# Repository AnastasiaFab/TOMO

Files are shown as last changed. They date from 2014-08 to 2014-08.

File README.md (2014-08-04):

TOMO

#### TOMO is a programmable Touch Synthesizer board based on Arduino. 

##### TOMO can sense your touch on many different materials and create sounds to tell people things.

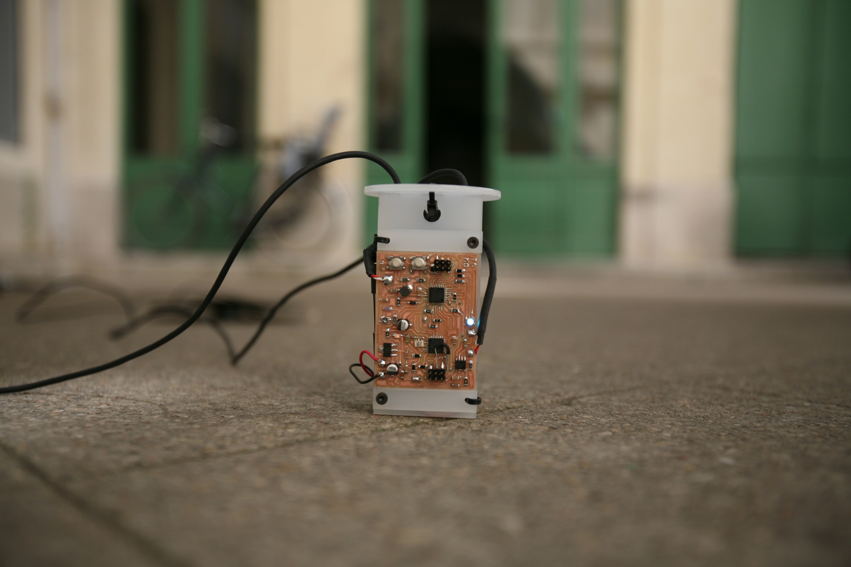
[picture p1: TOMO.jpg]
TOMO


### What is TOMO?

##TO

**TO** means touch. Tomo uses **Swept Frequency Capacitive Sensing (SFCS)** a concept explored by [Disney Research Labs](http://www.disneyresearch.com/) on this [paper](http://www.disneyresearch.com/wp-content/uploads/touchechi2012.pdf). The Arduino implementation is based on the documentation by [ILLUTRON](http://illutron.dk/Instructable-Use-Any-Surface-as-a-Touch-Interface-with-Arduino) and developed by [Cleniem](https://github.com/clemniem). The internal ongoing research on SFCS can be found at [fablabbcn/TouchE](https://github.com/fablabbcn/TouchE).

##MO

**MO** means [Mozzi](http://sensorium.github.io/Mozzi/) an amazing library for sound synthesis library for Arduino developed by [Tim Barrass](http://www.reverberant.com/pp/barrass.htm). This means you can create sounds with it from simple tones to delays and echos. We will soon add *.WAV palying functionality too.

### How is TOMO?

* Small
* Portable
* Easy
* Fun
* and it runs on batteries for a week!

### Project team:

This project was developed with the support of the [EASTN (The European Art-Science-Technology Network)](https://github.com/eastn.eu) at [Fab Lab Barcelona](http://www.fablabbcn.org/). The first real setup was done for the [FAV Festival](http://festivaldesarchitecturesvives.com/) in Monpellier in June 2014.

* [Cleniem](https://github.com/clemniem) 
* [Pral2a](https://github.com/pral2s)
* [Anastasia Pistofidou](https://github.com/anastasiafab)

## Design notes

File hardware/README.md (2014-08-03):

The TOMO board
==============

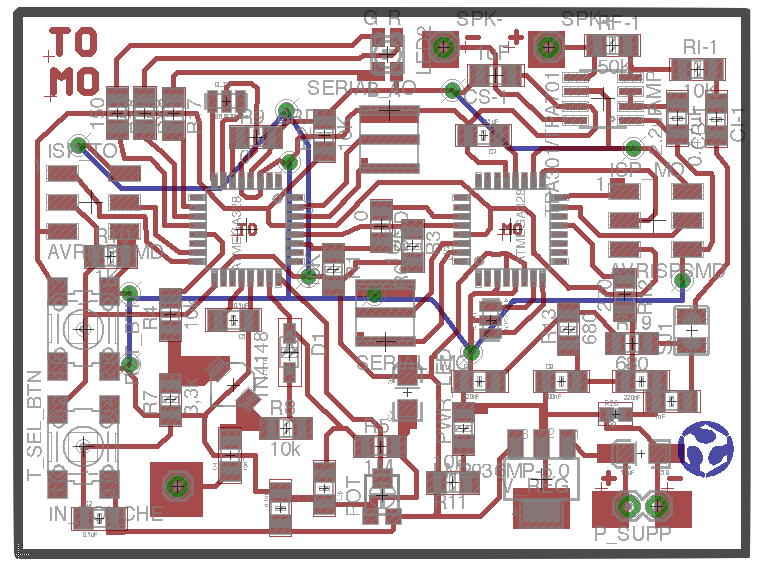
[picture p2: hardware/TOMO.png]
TOMO


Check the the Eagles and the PDF schematic for more information. 

Notice the PCB design is done to be milled on a PCB milling machine.

Check the CAM folder for the PNG for [FabModules](http://kokompe.cba.mit.edu/).

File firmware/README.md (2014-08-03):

The TOMO code
=============

**TOMO** has two processors this means it runs two separate firmwares: one for touch and one for sound.

## Firmware

Check the **TO** folder for the Touch firmware and the **MO** folder for the Mozzi Sound firmware. The sound firmware is currently a boilerplate for you to create your new sounds. Check on the **mozzi tests** folder for more examples.

* Touch firmware: `TOMO_Touch_v05.ino`

* Sound firmware: `TOMO_Mozzi_v05.ino` 

### Dependencies

All firmware is based on the Arduino Core. For the Mozzi firmware it requires the [Mozzi library](sensorium.github.io/Mozzi/)

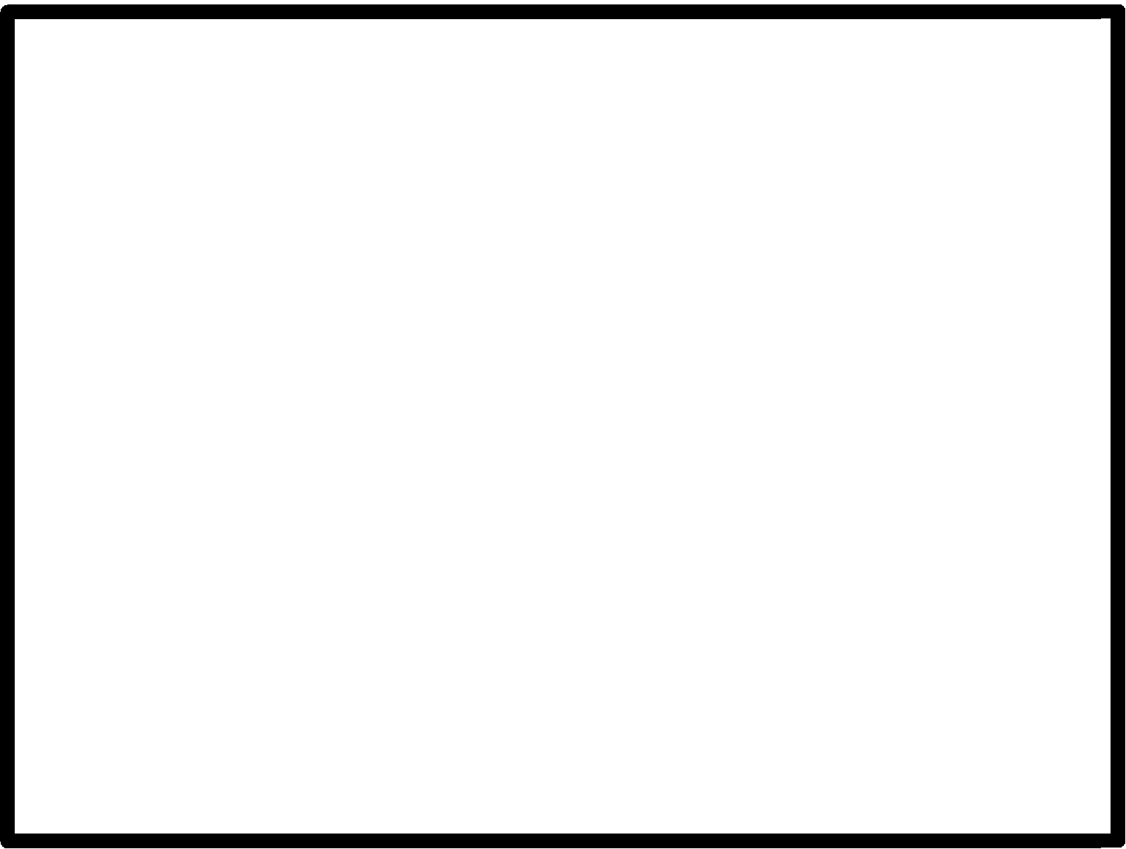
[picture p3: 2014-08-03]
hardware/CAM/TOMO_L1_CUT_1_32.png

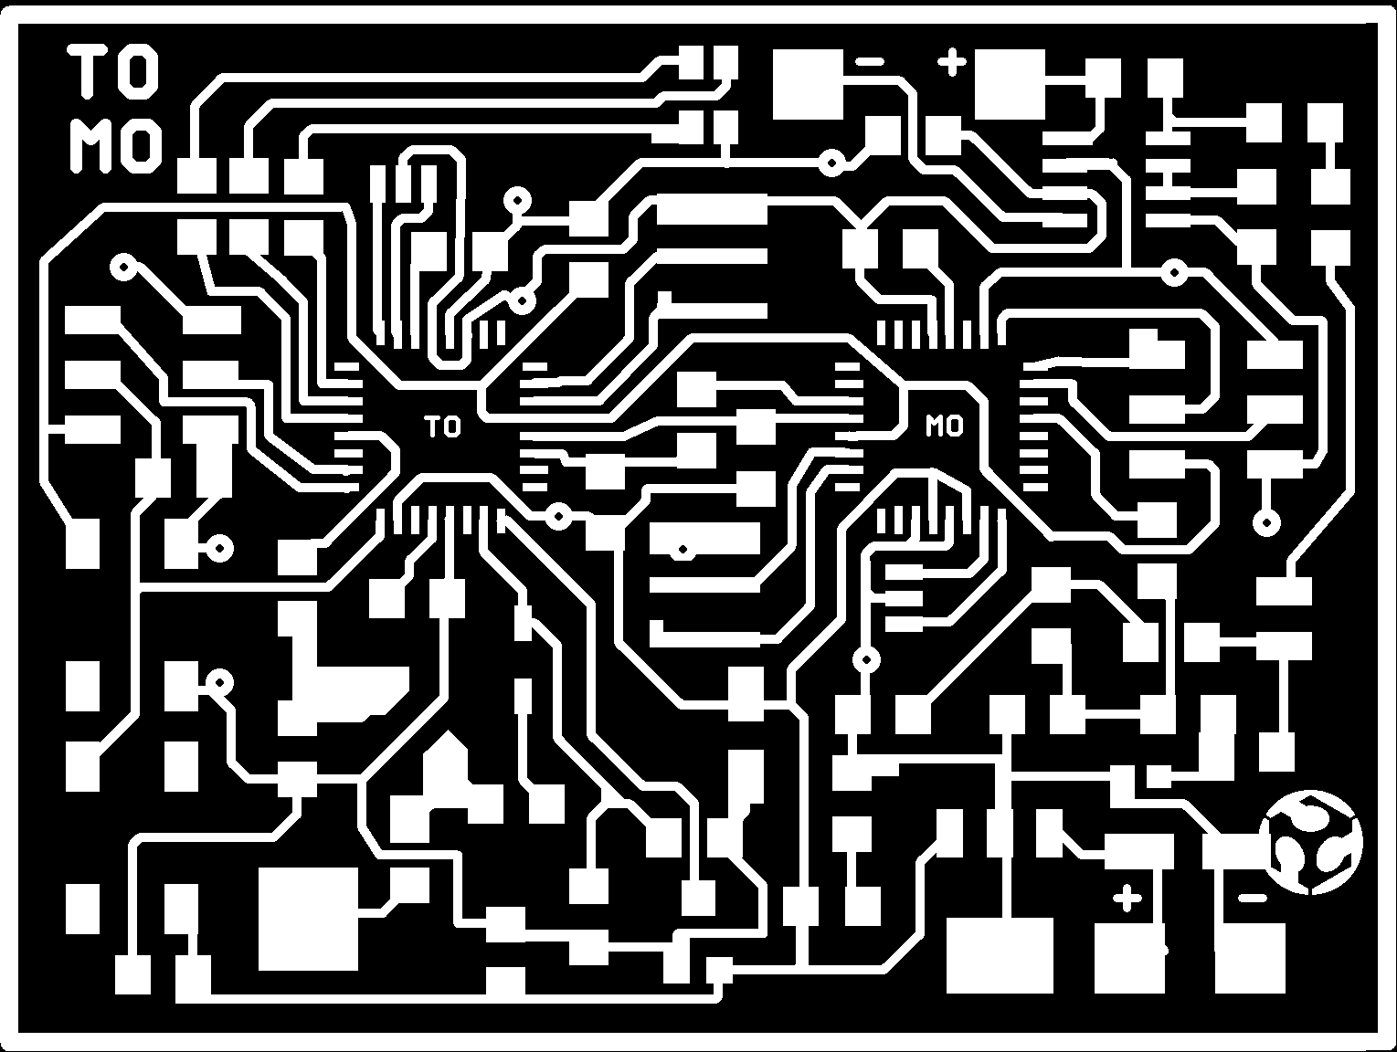
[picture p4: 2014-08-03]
hardware/CAM/TOMO_L1_ENG_1_64.png

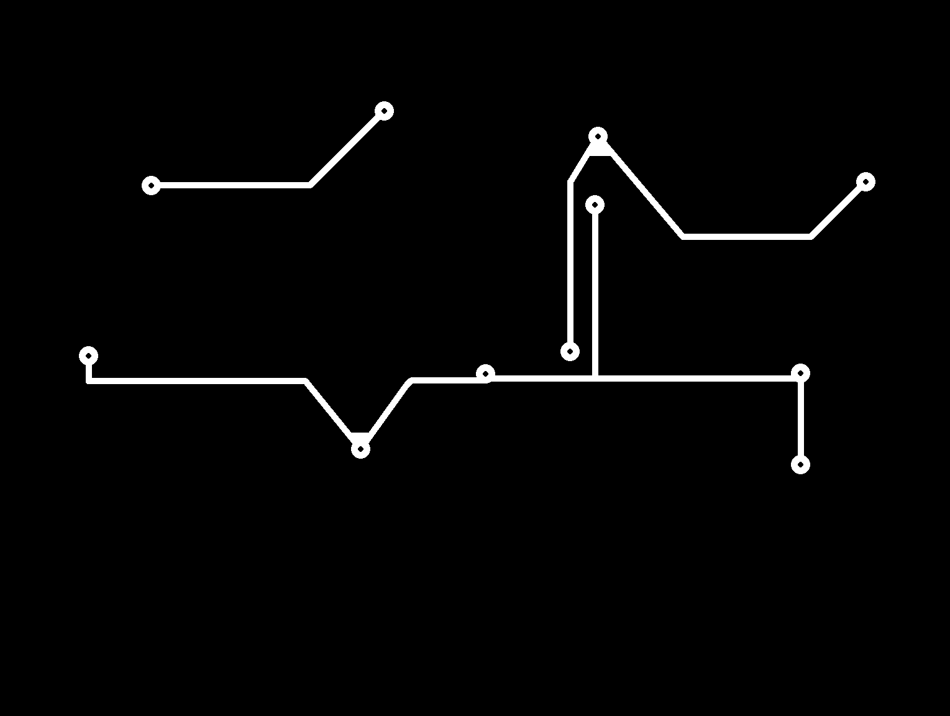
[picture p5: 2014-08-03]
hardware/CAM/TOMO_L2_ENG_1_64.png

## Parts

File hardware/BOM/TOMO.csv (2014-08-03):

Part | Value | Device | Package | Description | MF | MPN | OC_FARNELL | OC_NEWARK
AMP | TPA301/TPA701 | TPA301/TPA701 | SOIC8
C1 | 0.1uF | CAP1206 | 1206 | Capacitor
C2 | 0.1uF | CAP1206 | 1206 | Capacitor
C3 | 0.1uF | CAP1206 | 1206 | Capacitor
C4 | 10nF | CAP1206 | 1206 | Capacitor
C5 | 100p | CAP1206 | 1206 | Capacitor
C7 | 0.1uF | CAP1206 | 1206 | Capacitor
C8 | 220nF | CAP1206 | 1206 | Capacitor
C9 | 100nF | CAP1206 | 1206 | Capacitor
C12 | 220nF | CAP1206 | 1206 | Capacitor
C13 | 10uF | CAP_POL1206 | EIA3216 | Capacitor Polarized
C14 | 1nF | CAP1206 | 1206 | Capacitor
C19 | 10uF | CAP_POL1206 | EIA3216 | Capacitor Polarized
CB-1 | 2.2uF | C-USC1206 | C1206 | CAPACITOR, American symbol
CI-1 | 0.47uF | C-USC1206 | C1206 | CAPACITOR, American symbol
CS-1 | 1uF | C-USC1206 | C1206 | CAPACITOR, American symbol
D1 | 1N4148 | DIODESOD123 | SOD123 | DIODE
INDCTR |  | INDUCTOR | CDRH3D28 | Inductors
IN_TOUCHE |  | M01PTH | 1X01 | Header 1
ISP_MO | AVRISPSMD | AVRISPSMD | 2X03SMD
ISP_TO | AVRISPSMD | AVRISPSMD | 2X03SMD
LED2 |  | LEDRGBOLD | P-LCC-4-3 | OSRAM
POT |  | TRIMPOTTC33X | TC33X | SMT trimmer potentiometer part number TC33X
PWR_LED |  | LED1206 | 1206
P_SUPP |  | M02PTH | 1X02 | Header 2
Q_MO | 8/16/20MHz | RESONATORSMD | RESONATOR-SMD | Resonator
Q_TO | 8/16/20MHz | RESONATORSMD | RESONATOR-SMD | Resonator
R1 | 10K | RESISTOR1206 | 1206
R2 | 10K | RESISTOR1206 | 1206
R3 | 10K | RESISTOR1206 | 1206
R4 | 10k | RESISTOR1206 | 1206
R5 | 1M | RESISTOR1206 | 1206
R6_BRD | 0 | RESISTOR1206 | 1206
R7 | 3,3k | RESISTOR1206 | 1206
R8 | 10k | RESISTOR1206 | 1206
R9_BRD | 0 | RESISTOR1206 | 1206
R10 | 1K | RESISTOR1206 | 1206
R11 | 10K | RESISTOR1206 | 1206
R12 | 270 | RESISTOR1206 | 1206
R13 | 680 | RESISTOR1206 | 1206
R16 | 150 | RESISTOR1206 | 1206
R17 | 150 | RESISTOR1206 | 1206
R18 | 150 | RESISTOR1206 | 1206
R19 | 680 | RESISTOR1206 | 1206
R20 | 330 | RESISTOR0603-RES | 0603-RES | Resistor
RF-1 | 50K | R-US_R1206 | R1206 | RESISTOR, American symbol
RI-1 | 10K | R-US_R1206 | R1206 | RESISTOR, American symbol
RST_BTN |  | 6MM_SWITCH6MM_SWITCH | 6MM_SWITCH | OMRON SWITCH
SERIAL_MO |  | 3_PIN_HEADERHEADER | SMT_PINS_3 | 3 SMT pin pads
SERIAL_TO |  | 3_PIN_HEADERHEADER | SMT_PINS_3 | 3 SMT pin pads
SJ1 |  | SJW | SJW | SMD solder JUMPER
SPK+ |  | M01PTH | 1X01 | Header 1
SPK- |  | M01PTH | 1X01 | Header 1
T_SEL_BTN |  | 6MM_SWITCH6MM_SWITCH | 6MM_SWITCH | OMRON SWITCH
U1 | ATMEGA328 | ATMEGA168ATMEGA88THIN | ATMEGA88THIN
U3 | ATMEGA328 | ATMEGA168ATMEGA88THIN | ATMEGA88THIN
V_REG | LM2936MP-5.0 | LM2936MP-5.0 | SOT223 | Ultra-Low Quiescent Current LDO Voltage Regulator | NATIONAL SEMICONDUCTOR | LM2936MP-5.0/NOPB | 1469063 | 41K4524

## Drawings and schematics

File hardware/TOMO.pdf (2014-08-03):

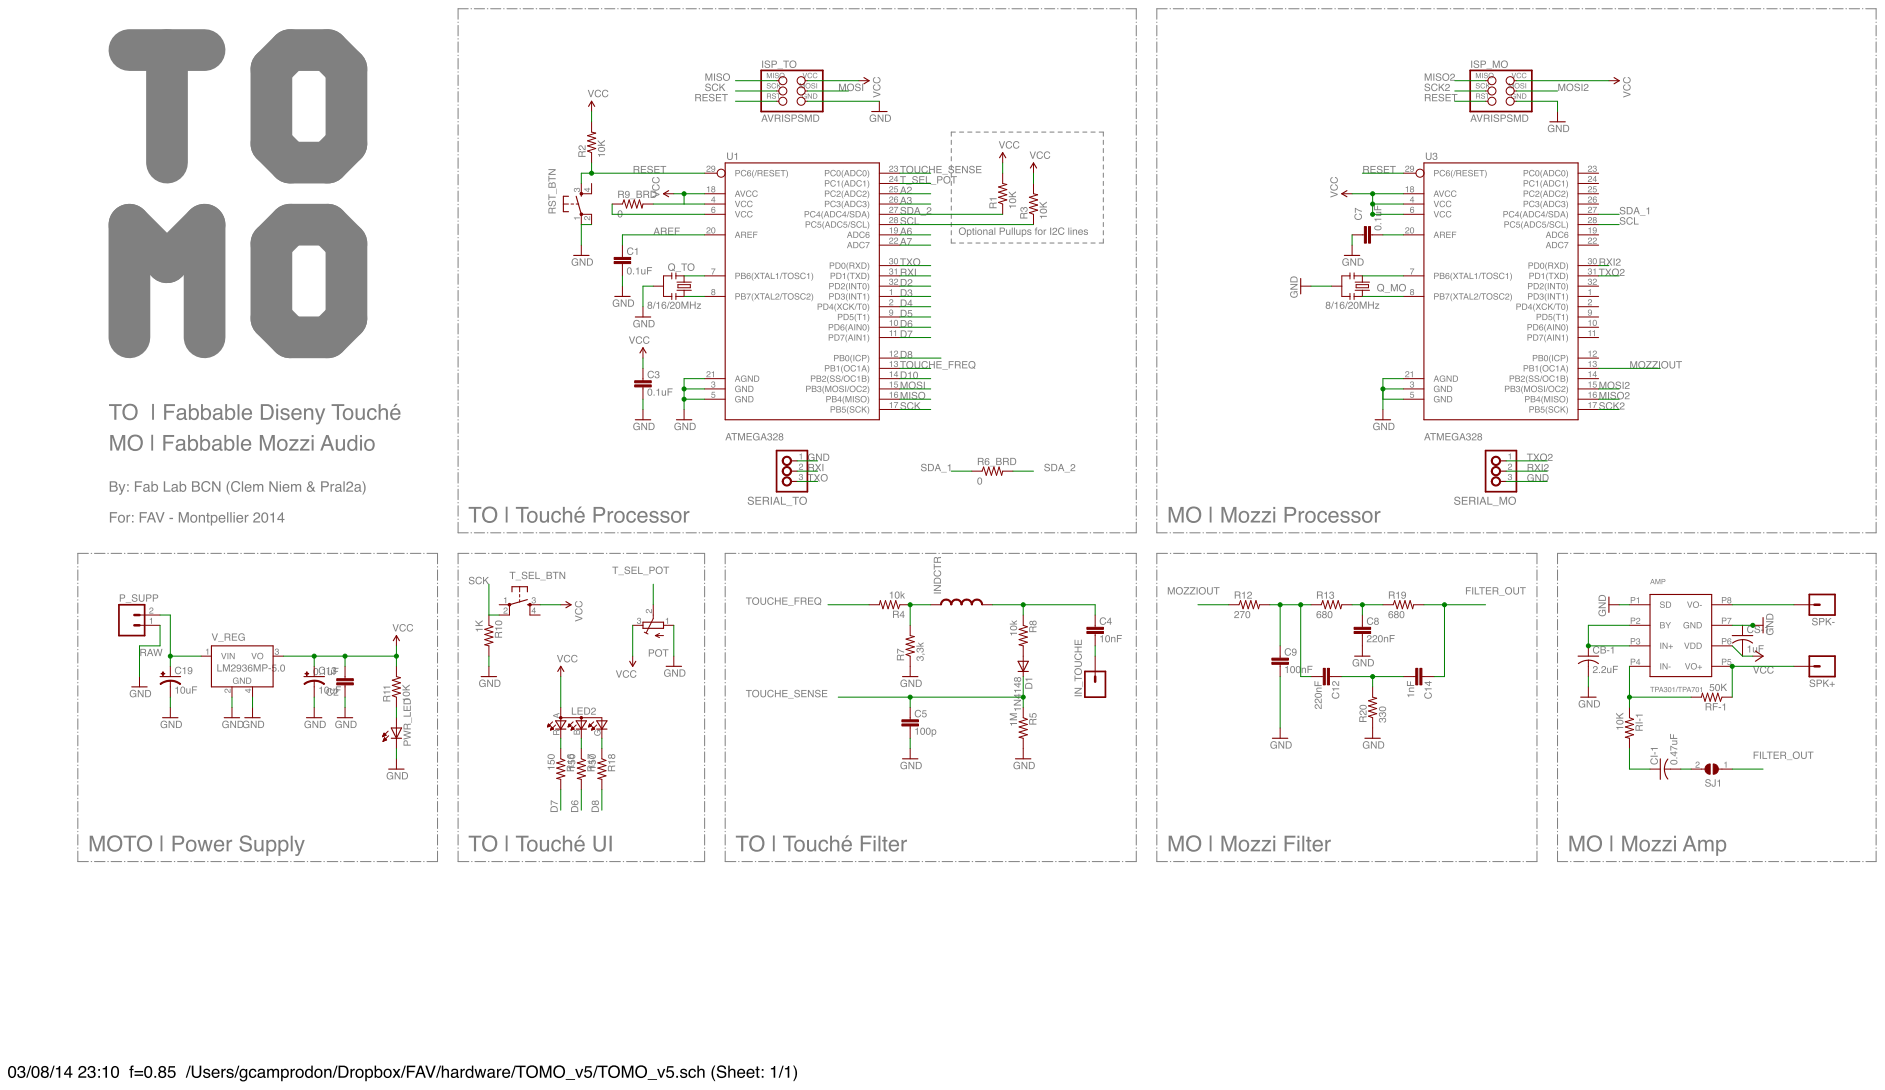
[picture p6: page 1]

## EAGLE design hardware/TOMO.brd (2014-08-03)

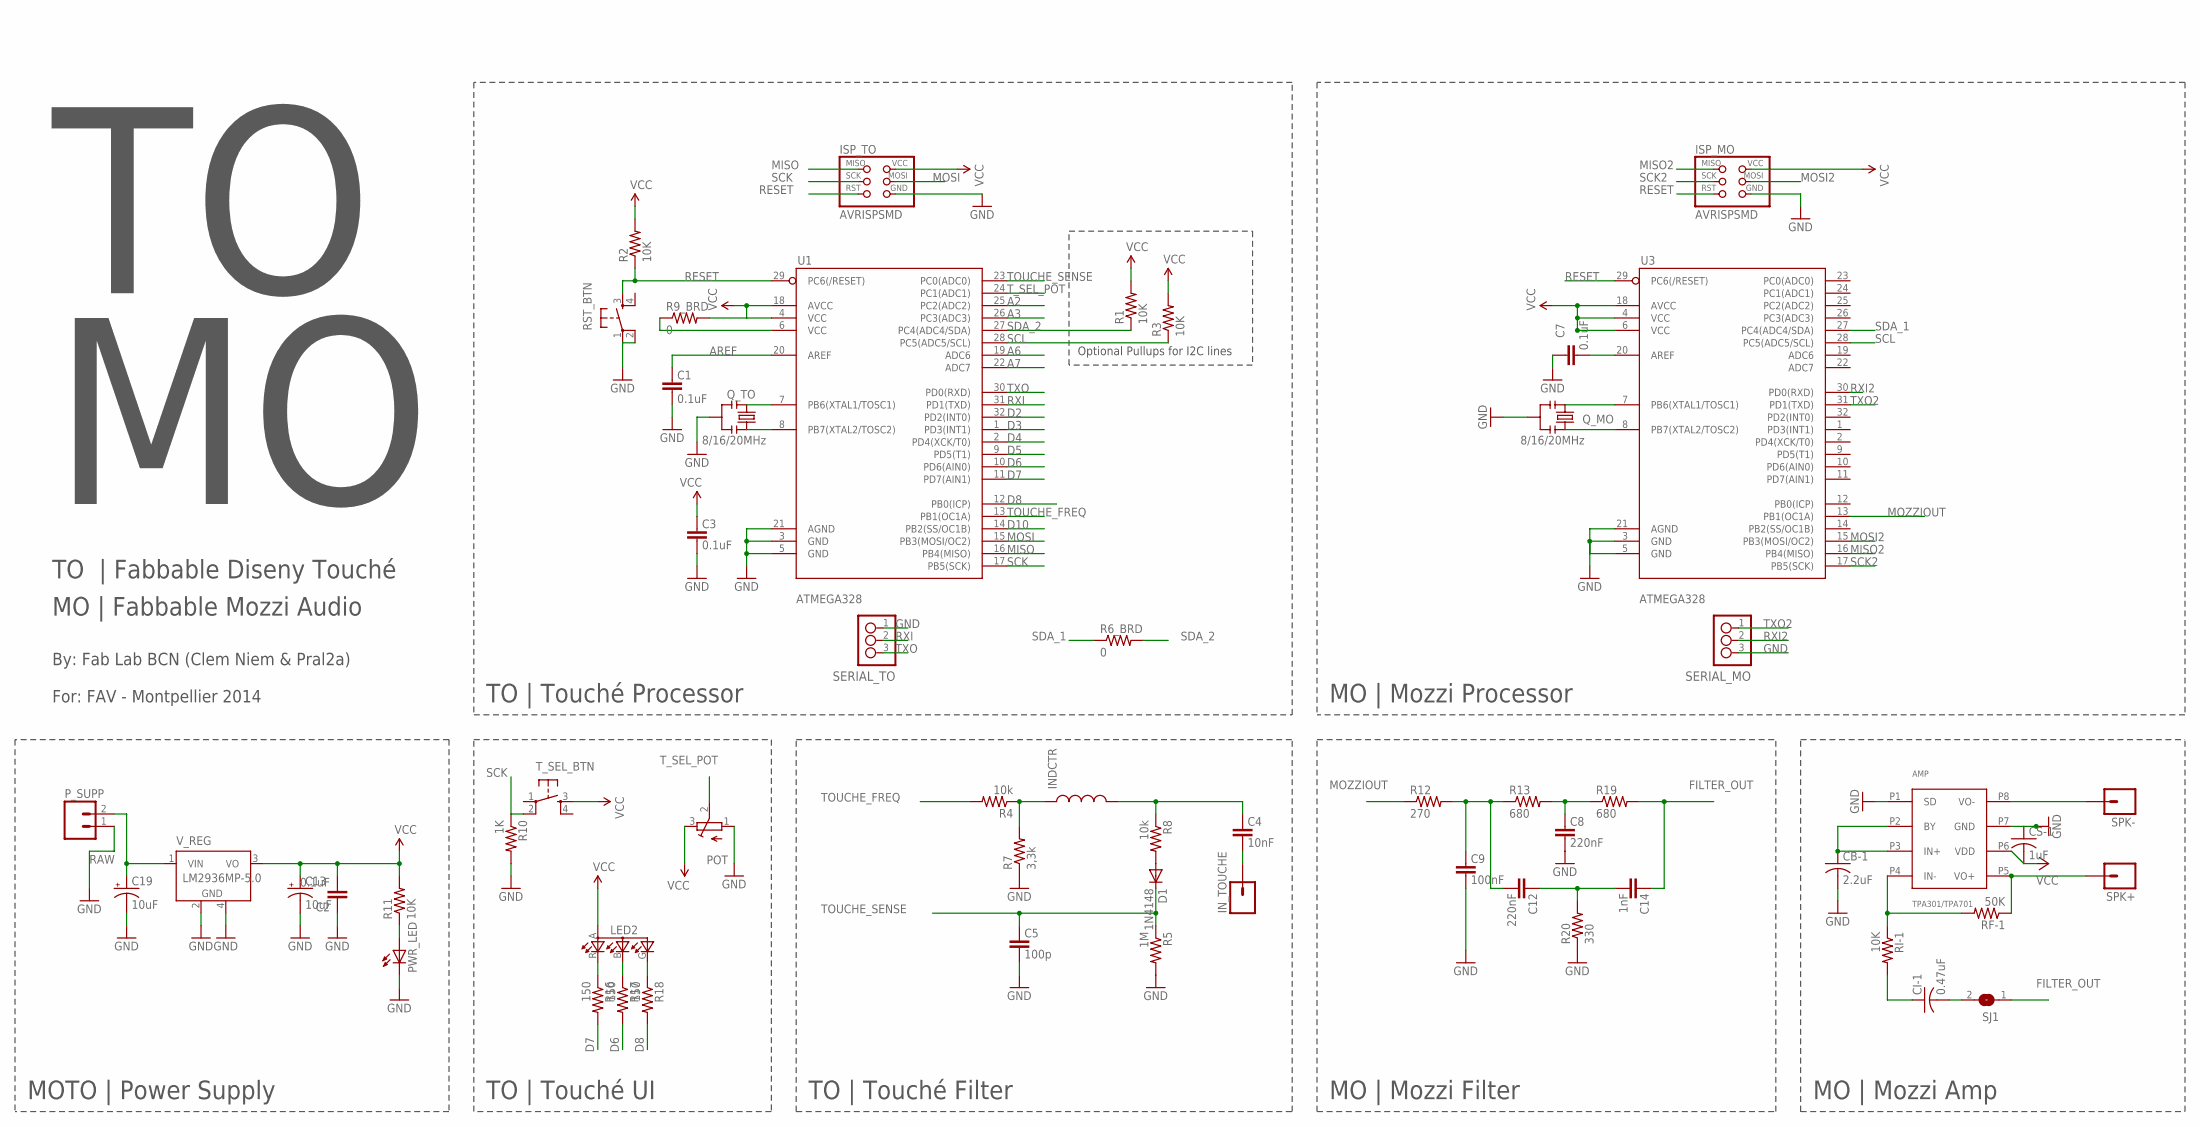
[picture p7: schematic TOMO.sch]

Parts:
AMP: TPA301/TPA701; SOIC8
C1, C2, C3, C7: 0.1uF; 1206
C4: 10nF; 1206
C5: 100p; 1206
C8, C12: 220nF; 1206
C9: 100nF; 1206
C13, C19: 10uF; EIA3216
C14: 1nF; 1206
CB-1: 2.2uF; C1206
CI-1: 0.47uF; C1206
CS-1: 1uF; C1206
D1: 1N4148; SOD123
INDCTR: INDUCTOR; CDRH3D28
IN_TOUCHE: M01PTH; 1X01
ISP_MO: AVRISPSMD; 2X03SMD
ISP_TO: AVRISPSMD; 2X03SMD
LED2: LEDRGBOLD; P-LCC-4-3
POT: TRIMPOTTC33X; TC33X
PWR_LED: LED1206; 1206
P_SUPP: M02PTH; 1X02
Q_MO: 8/16/20MHz; RESONATOR-SMD
Q_TO: 8/16/20MHz; RESONATOR-SMD
R1, R2, R3, R11: 10K; 1206
R4, R8: 10k; 1206
R5: 1M; 1206
R6_BRD, R9_BRD: 0; 1206
R7: 3,3k; 1206
R10: 1K; 1206
R12: 270; 1206
R13, R19: 680; 1206
R16, R17, R18: 150; 1206
R20: 330; 0603-RES
RF-1: 50K; R1206
RI-1: 10K; R1206
RST_BTN: 6MM_SWITCH6MM_SWITCH; 6MM_SWITCH
SERIAL_MO: 3_PIN_HEADERHEADER; SMT_PINS_3
SERIAL_TO: 3_PIN_HEADERHEADER; SMT_PINS_3
SJ1: SJW
SPK+: M01PTH; 1X01
SPK-: M01PTH; 1X01
T_SEL_BTN: 6MM_SWITCH6MM_SWITCH; 6MM_SWITCH
U1, U3: ATMEGA328; ATMEGA88THIN
V_REG: LM2936MP-5.0; SOT223

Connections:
A2: U1.25 (PC2(ADC2))
A3: U1.26 (PC3(ADC3))
A6: U1.19 (ADC6)
A7: U1.22 (ADC7)
AREF: C1.2, U1.20 (AREF)
D2: U1.32 (PD2(INT0))
D3: U1.1 (PD3(INT1))
D4: U1.2 (PD4(XCK/T0))
D5: U1.9 (PD5(T1))
D6: R17.2, U1.10 (PD6(AIN0))
D7: R16.2, U1.11 (PD7(AIN1))
D8: R18.2, U1.12 (PB0(ICP))
D10: U1.14 (PB2(SS/OC1B))
FILTER_OUT: C14.2, R19.2, SJ1.1
GND: AMP.P1 (SD), AMP.P7 (GND), C1.1, C2.1, C3.1, C5.1, C7.2, C8.1, C9.1, C13.C (-), C19.C (-), CB-1.2, CS-1.1, ISP_MO.6 (GND), ISP_TO.6 (GND), POT.1 (A), PWR_LED.2 (C), P_SUPP.1, Q_MO.2, Q_TO.2, R5.2, R7.1, R10.2, R20.1, RST_BTN.1, RST_BTN.2 (P1), SERIAL_MO.3, SERIAL_TO.1, U1.3 (GND), U1.5 (GND), U1.21 (AGND), U3.3 (GND), U3.5 (GND), U3.21 (AGND), V_REG.2 (GND), V_REG.4 (GND)
MISO: ISP_TO.1 (MISO), U1.16 (PB4(MISO))
MISO2: ISP_MO.1 (MISO), U3.16 (PB4(MISO))
MOSI: ISP_TO.4 (MOSI), U1.15 (PB3(MOSI/OC2))
MOSI2: ISP_MO.4 (MOSI), U3.15 (PB3(MOSI/OC2))
MOZZIOUT: R12.1, U3.13 (PB1(OC1A))
unnamed: Q_TO.1, U1.8 (PB7(XTAL2/TOSC2))
unnamed: CI-1.2, SJ1.2
unnamed: Q_TO.3, U1.7 (PB6(XTAL1/TOSC1))
unnamed: INDCTR.1, R4.1, R7.2
unnamed: C4.2, INDCTR.2, R8.1
unnamed: LED2.G (CGREEN), R18.1
unnamed: D1.ANODE (A), R8.2
unnamed: Q_MO.3, U3.7 (PB6(XTAL1/TOSC1))
unnamed: Q_MO.1, U3.8 (PB7(XTAL2/TOSC2))
unnamed: C12.2, C14.1, R20.2
unnamed: C4.1, IN_TOUCHE.1
unnamed: CI-1.1, RI-1.2
unnamed: LED2.R (CRED), R16.1
unnamed: C7.1, U3.20 (AREF)
unnamed: C9.2, C12.1, R12.2, R13.1
unnamed: LED2.B (CBLUE), R17.1
unnamed: R9_BRD.1, U1.6 (VCC)
unnamed: AMP.P4 (IN-), RF-1.2, RI-1.1
unnamed: C8.2, R13.2, R19.1
unnamed: AMP.P2 (BY), AMP.P3 (IN+), CB-1.1
unnamed: PWR_LED.1 (A), R11.1
RAW: C19.A (+), P_SUPP.2, V_REG.1 (VIN)
RESET: ISP_MO.5 (RST), ISP_TO.5 (RST), R2.1, RST_BTN.3 (S), U1.29 (PC6(/RESET)), U3.29 (PC6(/RESET))
RXI: SERIAL_TO.2, U1.31 (PD1(TXD))
RXI2: SERIAL_MO.2, U3.30 (PD0(RXD))
SCK: ISP_TO.3 (SCK), R10.1, T_SEL_BTN.2 (P1), U1.17 (PB5(SCK))
SCK2: ISP_MO.3 (SCK), U3.17 (PB5(SCK))
SCL: R3.1, U1.28 (PC5(ADC5/SCL)), U3.28 (PC5(ADC5/SCL))
SDA_1: R6_BRD.1, U3.27 (PC4(ADC4/SDA))
SDA_2: R1.1, R6_BRD.2, U1.27 (PC4(ADC4/SDA))
SPK_L+: AMP.P5 (VO+), RF-1.1, SPK+.1
SPK_L-: AMP.P8 (VO-), SPK-.1
TOUCHE_FREQ: R4.2, U1.13 (PB1(OC1A))
TOUCHE_SENSE: C5.2, D1.CATHODE (C), R5.1, U1.23 (PC0(ADC0))
TXO: SERIAL_TO.3, U1.30 (PD0(RXD))
TXO2: SERIAL_MO.1, U3.31 (PD1(TXD))
T_SEL_POT: POT.2 (S), U1.24 (PC1(ADC1))
VCC: AMP.P6 (VDD), C2.2, C3.2, C13.A (+), CS-1.2, ISP_MO.2 (VCC), ISP_TO.2 (VCC), LED2.A (A2), POT.3 (E), R1.2, R2.2, R3.2, R9_BRD.2, R11.2, T_SEL_BTN.3 (S), U1.4 (VCC), U1.18 (AVCC), U3.4 (VCC), U3.6 (VCC), U3.18 (AVCC), V_REG.3 (VO)

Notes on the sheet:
Optional Pullups for I2C lines
TO | Touché Filter
TO | Touché Processor
MO | Mozzi Processor
TO | Touché UI
MO | Mozzi Filter
MO | Mozzi Amp
MOTO | Power Supply
TO | Fabbable Diseny Touché
MO | Fabbable Mozzi Audio
By: Fab Lab BCN (Clem Niem & Pral2a)
For: FAV - Montpellier 2014

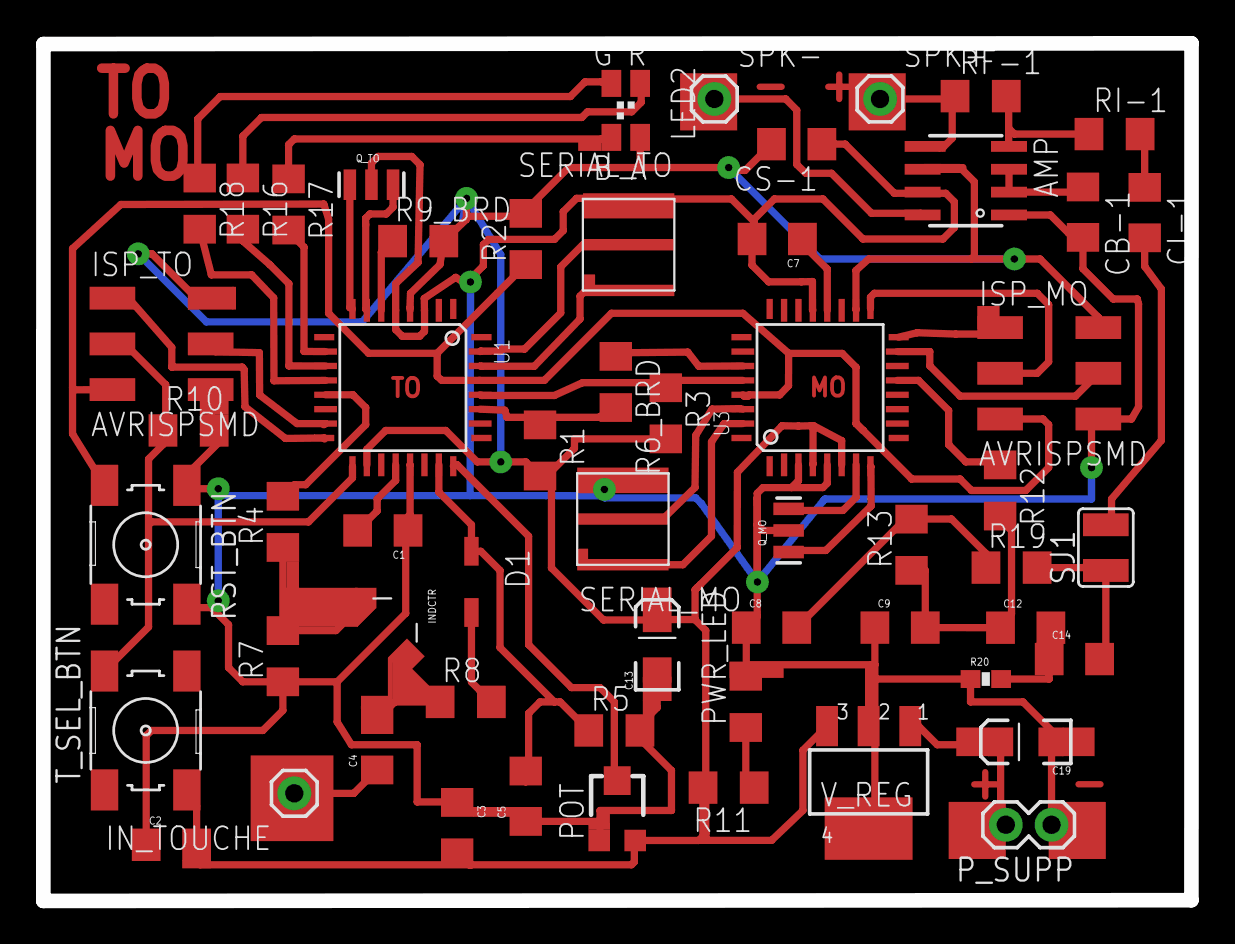
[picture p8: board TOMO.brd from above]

Board: 2 copper layers, 63.8 x 47.6 mm, 57 parts (0 on the bottom side), 49 nets.

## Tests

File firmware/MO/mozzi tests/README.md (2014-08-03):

MOZZI
=====

Various sound tests based on the [Mozzi](http://sensorium.github.io/Mozzi/) library for Arduino for the TOMO board.

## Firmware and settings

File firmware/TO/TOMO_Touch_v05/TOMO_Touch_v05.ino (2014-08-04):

/*

   _______  _______ 
  |       ||       |  Arduino based Touch Synthesizer
  |_     _||   _   |   
    |   |  |  | |  |  TOUCH FIRMWARE v0.5
    |   |  |  |_|  |
    |   |  |       |
    |___|  |_______|   Based on:
   __   __  _______ 
  |  |_|  ||       |   Illutron take on Disney Touch style capacitive touch sensor
  |       ||   _   |   using only passives and Arduino  Dzl 2012
  |       ||  | |  |
  |       ||  |_|  |   Developed by:
  | ||_|| ||       |
  |_|   |_||_______|   FabLabBCN && clemniem 2014
  
  Sweep Capacitances Features:
                      
  1. Store & Calculate all Values on the Arduino
  2. Enhance Resolution through comparing Arrays rather than Maxima 
   
   https://github.com/clemniem/fabTouche
   https://github.com/fablabbcn/TouchE

*/

#define SET(x,y) (x |=(1<<y))				//-Bit set/clear macros
#define CLR(x,y) (x &= (~(1<<y)))       		// |
#define CHK(x,y) (x & (1<<y))           		// |
#define TOG(x,y) (x^=(1<<y))            		//-+

//-----------Changeable Variables-----------------<<----<<--
#define N 120             //How many frequencies (max depends on memory and NUMBER)
#define NUMBER 3          // How Many Buttons(States)
#define CALIBRATION 100   // Define Calibration Here (From 0-255) Best works ~100-180



//----------------Include Libraries needed------------------
#include <EEPROM.h>
#include <Wire.h>

//----------------Measure Values----------------------------
int results[N];         //-Filtered result buffer
int freq[N];            //-Filtered result buffer
int sizeOfArray = N;
byte counter = 0;

//----------------Store Norm Values-------------------------
int baseline[N]; // baseline
int button1 = 2; // Change Pins accordingly
int button2 = 4; // "
int button3 = 6; // "
int buttons[] = {button1 , button2, button3};  // add additional Buttons
//byte saveButton = 3; // To store away Values in EEPROM
byte buttonPin = 13;
int addr = 0;

//-----Calculate Current Area Differences----------------------
byte areaDiffTemp[N]; // Aray to store current AreaDifferences

// -----------Store current Area Differences Values------------
byte areaDifferences[NUMBER][N];      // Array to store the AreaDifference for each Frequency per State
byte areaDifferencesSum[NUMBER][1];
//byte lastButtonState[] ={LOW,LOW,LOW};
byte lastButtonState = 0;    //
int buttonPushCounter = 0;   // counter for the number of button presses
byte buttonState = LOW;
unsigned long previousMillis = 0;
int tempAD;
//------------------------Compare------------------
int currentOutput = 0;
int output = 0;
byte stateOutput = 0;
byte stateOutputs[3] = {0,0,0};
//-------------------Output------------------------
int output1 = 6;  // 6 = Red
int output2 = 7;  // 7 = Blue
int output3 = 8;  // 8 = Green
int outputs[] = {output1, output2, output3}; // add additional Outputs

//......................Output...END...............


void setup()
{
  //-----------------------Touche by Illutron-----------------------
  TCCR1A=0b10000010;        //-Set up frequency generator
  TCCR1B=0b00011001;        //-+
  ICR1=110;
  OCR1A=55;
  
  pinMode(9,OUTPUT);        //-Signal generator pin
  Serial.begin(9600);
  
  for(byte i=0;i<N;i++) results[i]=0;//-Preset results 
    
  //-------------------------FabTouche by FabLabBCN-----------------
  
  Wire.begin(4);                // join i2c bus (address optional for master)
  Wire.onRequest(requestEvent); // register event

  pinMode(button1, INPUT);     // Setup Input Buttons
  pinMode(button2, INPUT);     // |
  pinMode(button3, INPUT);     //-+

  pinMode(output1, OUTPUT);    // Setup Output Buttons
  pinMode(output2, OUTPUT);    // |
  pinMode(output3, OUTPUT);    //-+
  
  for(byte d=0;d<N;d++){
    baseline[d] = 0;           //Preset-values for baseline
  }
  
  for(byte i=0;i<NUMBER;i++){  // Restore saved areaDifferences from EEPROM
    for(byte d=0;d<N;d++){
      //addr = (d+i*N);
      areaDifferences[i][d] = EEPROM.read(d+i*N);
    }
  }
}

void loop(){

//============Refreshing TempValues========================
//  byte tempAD = 0;
  byte tempAreaDifference = 0;
  currentOutput = -1;
  
//  if(digitalRead(saveButton)){
//    saveButtonRoutine();
//  }
  
//   

//=====================Measure Values======================
  for(byte d=0;d<N;d++){
    int v=analogRead(A0);                   //-Read response signal
    CLR(TCCR1B,0);                          //-Stop generator
    TCNT1=0;                                //-Reload new frequency
    ICR1=d;                                 // |
    OCR1A=d/2;                              //-+
    SET(TCCR1B,0);                          //-Restart generator
    results[d]=results[d]*0.5+(int)(v)*0.5; //Filter results
    freq[d] = d;
  }

  
//===========Store "Zero"-Values (in baseline)=============
  if(counter <= 5){ // for 5 cicles save the zero value
    for(byte d=0;d<N;d++){
      baseline[d] = results[d];
    }
    counter++;
    if(counter == 6){
      saveAreaDiffArray(0); // Store the No-Touch-Value     
      Serial.println("0"); 
      flash(3);
    }
  }
  
//==================Calculate Current AreaDiff================
  for(byte d=0;d<N;d++){
    tempAD = (byte) abs(results[d]-baseline[d]); // Difference between the current (results) and the stored "Zero"-Values (baseline)
    areaDiffTemp[d] = tempAD;
  }

//===============Store Current AreaDiff=========================
//  for(byte i=0;i<NUMBER;i++){        // When a Button gets pressed the Current areaDifferences are 
//    buttonState = digitalRead(buttons[i]);
//    if(buttonState != lastButtonState[i]){  //stored in the Array related to that Button
//      lastButtonState[i] = buttonState;
//      if(buttonState == HIGH){
//        saveAreaDiffArray(i);
//      }  
//    }
//  }
  
  //-----
  buttonState = digitalRead(buttonPin);

  unsigned long currentMillis = millis();

  if (buttonState != lastButtonState) {
    if (buttonState == HIGH) {
      buttonPushCounter++;
      previousMillis = currentMillis;   
    } 
  }

  lastButtonState = buttonState;

  if(currentMillis - previousMillis > 1000 && buttonPushCounter > 0) {
    if (buttonPushCounter == 1) {
      saveAreaDiffArray(1);
      Serial.println("1");
    } 
    else if (buttonPushCounter == 2) {
      saveAreaDiffArray(2);
      Serial.println("2");
    }
    else if (buttonPushCounter >= 3) {
      saveButtonRoutine();
      Serial.println("SAVE");
    }
    buttonPushCounter = 0;
  }

//===============Compare AreaDifferences============================ 
  for(byte i=0;i<NUMBER;i++){
    //int calibrationPot = analogRead(A1);        // You can also add a potentiometer to A1 and try calibrating it this way 
    output = 0;                                   // Refresh Temp Value
    int tempOutput = 0;                           // "
    for(byte d=0;d<N;d++){
      tempOutput = abs(areaDifferences[i][d] - areaDiffTemp[d]);  //Calculate Differece between values for this frequency and
                                                                  //save it away in tempOutpout
      if(tempOutput > CALIBRATION){                               //check if difference is bigger than CALIBRATION/calibrationPot (if potentiometer on A1)
        output += tempOutput;                                     //accumulate Area of values that are bigger
      }
    }  
    areaDifferencesSum[i][0] = output;
    if(output < currentOutput || currentOutput < 0){ //Compare the areas. The number of the lowest (=most corresponding) 
      currentOutput = output;                        //will be saved in stateOutput
      stateOutput = i;
    }
  }

//=====================Output=========================
  byte actualOutput = outputs[stateOutput]; //convert State to the corresponding output Pin
  for(byte i=0;i<NUMBER;i++){               //Refresh outputs. All on LOW
    digitalWrite(outputs[i],HIGH);
  }
  digitalWrite(actualOutput, LOW);         // Put current OutputState to HIGH
  
  stateOutputs[2] = stateOutputs[1];
  stateOutputs[1] = stateOutputs[0];
  stateOutputs[0] = stateOutput;
//  Serial.print("[");
//  Serial.print(stateOutputs[0]);
//  Serial.print(",");
//  Serial.print(stateOutputs[1]);
//  Serial.print(",");
//  Serial.print(stateOutputs[2]);
//  Serial.print("]");  
  
////==================printOut for Debugging============
//  for(byte i=0;i<NUMBER;i++){
//    Serial.print("i: ");
//    Serial.print(i)
//    Serial.print(" : ")
//    Serial.print(areaDifferencesSum[i][0])
//    Serial.print(" || ")
//  }
//  Serial.println("-------------------------------");

}

// -----------------------------
// Function that Flashes n-times with all LEDs, for debugging
void flash(int times){
  for(byte i=0;i<times;i++){
    for(byte i = 0;i<NUMBER;i++){        
      digitalWrite(outputs[i],LOW);
    }
    delay(50);
    for(int i = 0;i<NUMBER;i++){        
      digitalWrite(outputs[i],HIGH);
    }
    delay(50); 
  }  
}

//------------------------------
// saves away the current areaDifferences into the states array
void saveAreaDiffArray(byte state){
  for(byte d=0;d<N;d++){
    areaDifferences[state][d] = areaDiffTemp[d];
  }
  flash(2);
}

//------------------------------
//stores Away the AreaDifferences in the EEPROM 




void saveButtonRoutine(){
  for(byte i=0;i<NUMBER;i++){
    for(byte d=0;d<N;d++){
      EEPROM.write((d+i*N), areaDifferences[i][d]);  //addr = (d+i*N); b1 => 0-N; b2 => N+1-2N; b3 => (2N+1)-3N 
    }
  }
  flash(5);
}

//------------------------------
//sends the last three states, which are saved in stateOutputs to the wire as slave
void requestEvent()
{
  Wire.write(stateOutputs, 3); // sends one byte  
}

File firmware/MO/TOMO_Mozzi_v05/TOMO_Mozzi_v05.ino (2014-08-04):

/*
   _______  _______ 
  |       ||       |   Arduino based Touch Synthesizer
  |_     _||   _   |   
    |   |  |  | |  |   MOZZI FIRMWARE v0.5
    |   |  |  |_|  |
    |   |  |       |  
    |___|  |_______|   Based on:
   __   __  _______ 
  |  |_|  ||       |   Mozzi I2C communication by Marije Baalman 2012.
  |       ||   _   |   Small modifications by TIm Barrass to retain Mozzi compatibility.
  |       ||  | |  |
  |       ||  |_|  |   Developed by:
  | ||_|| ||       |   FabLabBCN && clemniem 2014
  |_|   |_||_______|
    
*/

#include <MozziGuts.h>
#include <Oscil.h> // oscillator template
#include <tables/sin2048_int8.h> // sine table for oscillator
#include <twi_nonblock.h>

#define CONTROL_RATE 128 // powers of 2 please

// use: Oscil <table_size, update_rate> oscilName (wavetable), look in .h file of table #included above
Oscil <SIN2048_NUM_CELLS, AUDIO_RATE> aSin(SIN2048_DATA);



#define SLAVE_SENDER_DEVICE 4   // Touche device address
#define SENT_BYTES 3  //The Number of Bytes you want to send and receive
#define VOLUME 80     //Set Output Volume


static volatile uint8_t acc_status = 0;
#define ACC_IDLE 0
#define ACC_READING 1
#define ACC_WRITING 2

uint8_t receivedBytes[SENT_BYTES]; // Array to store your received bytes

void setup_wire(){
  initialize_twi_nonblock();

  acc_status = ACC_IDLE;
}

/// ---------- non-blocking version ----------
void initiate_read_wire(){
  // Reads num bytes starting from address register on device in to _buff array
  // indicate that we are transmitting
  //   transmitting = 1;
  // set address of targeted slave
  txAddress = SLAVE_SENDER_DEVICE;
  // reset tx buffer iterator vars
  txBufferIndex = 0;
  txBufferLength = 0;  

  // put byte in tx buffer
  byte x = 0;
  txBuffer[txBufferIndex] = x; //>>>>>>>>???<<<<<<<<<<<<<<<<<<<<<<<<<<<<<<<<<<<<<
  ++txBufferIndex;
  // update amount in buffer   
  txBufferLength = txBufferIndex;

  twi_initiateWriteTo(txAddress, txBuffer, txBufferLength);
  acc_status = ACC_WRITING;
}

void initiate_request_wire(){
  // reset tx buffer iterator vars
  txBufferIndex = 0;
  txBufferLength = 0;
  // indicate that we are done transmitting
  //   transmitting = 0;

  uint8_t read = twi_initiateReadFrom(SLAVE_SENDER_DEVICE, SENT_BYTES);
  acc_status = ACC_READING;
}

void finalise_request_wire(){
  uint8_t read = twi_readMasterBuffer( rxBuffer, SENT_BYTES);

  // set rx buffer iterator vars
  rxBufferIndex = 0;
  rxBufferLength = read;

  uint8_t i = 0;
  while( rxBufferLength - rxBufferIndex > 0)         // device may send less than requested (abnormal)
  { 
    receivedBytes[i] = rxBuffer[rxBufferIndex];
    ++rxBufferIndex;
    i++;
  }
  //-----------------------PRINTOUT for DEBUGGING-------------------------
//  Serial.print("[");
//  for(int i = 0;i<SENT_BYTES;i++){
//    Serial.print(receivedBytes[i]);
//    Serial.print(",");
//  }
//  Serial.print("]");
//  Serial.println();
//  Serial.println("-------------");
  //----------------------------------------------------------------------
  
  acc_status = ACC_IDLE;
}
/// ----end------ non-blocking version ----------

// Writes val to address register on device
void device_writeTo(byte address, byte val) {
  //   Wire.beginTransmission(SLAVE_SENDER_DEVICE); // start transmission to device   
  twowire_beginTransmission(SLAVE_SENDER_DEVICE); // start transmission to device   
  //   Wire.send(address);             // send register address
  twowire_send( address );
  //   Wire.send(val);                 // send value to write
  twowire_send( val );  
  //   Wire.endTransmission();         // end transmission
  twowire_endTransmission();
}


void setup(){
  Serial.begin(9600);
  setup_wire();
  startMozzi(CONTROL_RATE);
  aSin.setFreq(800);
}

int accx = 0;


void updateControl(){  
  if (accx == 0){
    aSin.setFreq( 800 );
  } 
  else if (accx == 1) {
    aSin.setFreq( 1000  );
  } 
  else if (accx == 2) {
    aSin.setFreq( 1400 );
  }
//------StateMachine----------------------------------------------------------------
  switch( acc_status ){
  case ACC_IDLE:
    //------------------Update your Variable from the array --------
    accx = (int) (receivedBytes[0]); // receivedBytes[0] x reading
    //--------------------------------------------------------------
    initiate_read_wire();
    break;
  case ACC_WRITING:
    if ( TWI_MTX != twi_state ){
      initiate_request_wire();
    }
    break;
  case ACC_READING:
    if ( TWI_MRX != twi_state ){
      finalise_request_wire();
    }
    break;
  }
 //-----------------------------------------------------------------------
}


int updateAudio(){
  return (aSin.next()*VOLUME)>>8;
}


void loop(){
  audioHook(); // required here
}

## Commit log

2014-08-03 TOMO is alive
    [TOMO.brd, TOMO.csv, TOMO.sch]
2014-08-04 Correcting some wrong namings
    [TOMO_Mozzi_v05.ino, TOMO_Touch_v05.ino]

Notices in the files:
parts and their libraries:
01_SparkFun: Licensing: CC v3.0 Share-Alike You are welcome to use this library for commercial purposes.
